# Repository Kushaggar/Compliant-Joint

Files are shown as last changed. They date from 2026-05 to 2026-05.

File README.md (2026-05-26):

# Translational Constraint Joint with 5 Degrees of Freedom

**Research Project | Mechatronics Lab, IIT Delhi**
**Supervised by Prof. Jitendra P. Khatait & Subrat (PhD Student)**

A compliant mechanism designed to constrain translation along the Y-axis while 
allowing controlled motion across 4 remaining DOFs. Stiffness values were derived 
analytically and validated against ANSYS static structural simulations.

---

## Overview

Traditional joints rely on sliding or rolling contact to guide motion — introducing 
friction, wear, and assembly complexity. This compliant mechanism achieves the same 
constraint behavior through elastic deformation of flexible members, with no moving 
parts, no lubrication, and no assembly required.

The joint constrains **1 DOF (Translation in Y)** while permitting:
- Rotation in X or Z axis
- Rotation in Y axis
- Translation in X axis
- Translation in Z axis

---

## Geometry

| Parameter | Value |
|---|---|
| Outer Diameter | 25 mm |
| Total Length | 106 mm |
| Flexure Thickness (t) | 0.50 mm |
| Flexure Radius (r) | R1.50 mm |
| Inner Radius | R5.00 mm |

---

## Specifications

| Motion | Displacement Range | Stiffness (Simulation) | Stiffness (Analytical) | Max Stress |
|---|---|---|---|---|
| Rotation X or Z | ±2.2° | 16.6 Nm/rad | 18.1 Nm/rad | 167.36 MPa |
| Rotation Y | ±4.6° | 21.86 Nm/rad | 21.81 Nm/rad | 308.35 MPa |
| Translation X | ±0.5 mm | 35.3 N/mm | 40.6 N/mm | 186.61 MPa |
| Translation Z | ±0.5 mm | 19.318 N/mm | 21.34 N/mm | 162.13 MPa |
| Translation Y | Constrained | 84745.76 N/mm | 94339.62 N/mm | — |

---

## Analytical Formulations

**Rotation in X or Z Axis:**

$$\theta = \sin^{-1}\left(\frac{l+r+t}{\sqrt{(l+r)^2+\left(\frac{d}{2}\right)^2}}\right) - \sin^{-1}\left(\frac{l+r}{\sqrt{(l+r)^2+\left(\frac{d}{2}\right)^2}}\right)$$

**Rotation in Y Axis:**

$$\theta = \sin^{-1}\left(\frac{2t}{\sqrt{t^2+\left(\frac{d}{2}\right)^2}}\right) - \sin^{-1}\left(\frac{t}{\sqrt{t^2+\left(\frac{d}{2}\right)^2}}\right)$$

**Translation in X or Z Axis:**

$$\delta = \pm t$$

---

## Simulation vs Analytical — Summary

| Motion | % Error |
|---|---|
| Rotation X/Z | 9% |
| Rotation Y | 0.2% |
| Translation X | 15% |
| Translation Z | 10% |
| Translation Y | 11.3% |

All results within acceptable range for compliant mechanism design at this scale.
Rotation Y shows near-perfect agreement (0.2%) between simulation and analytical model.

**Critical Buckling Load (Translation Y, Euler's formula):** 2.3 × 10⁴ N

---

## Tools & Methods
- **CAD:** SolidWorks
- **Simulation:** ANSYS Workbench — Static Structural
- **Validation:** Analytical beam theory (ML/EI, PL³/3EI, torsion stiffness formulations)

---

## Files

| File | Description |
|---|---|
| *5 DOF* | SolidWorks part file |
| `5 DOF.pdf` | Drawing file |
| `Translation Constraint Joint with 5 DOF.pdf` | Full project report with simulation results |

---

## Context
This work was completed during a research internship at the **Mechatronics Lab, IIT Delhi**
under the supervision of **Prof. Jitendra P. Khatait**.

**Portfolio:** [kushank.vercel.app](https://kushank.vercel.app)

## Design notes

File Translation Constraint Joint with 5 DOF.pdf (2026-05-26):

# Translation Constraint Joint with Five Degrees of Freedom

## A Report

by

# Kushank Aggarwal

## (B.tech student at Delhi Technological University)

## (Intern at Mechatronics Lab, IIT Delhi)

## Supervised by

# Prof. Jitendra P. Khatait

# Subrat (Ph.D Student)

# CAD MODEL

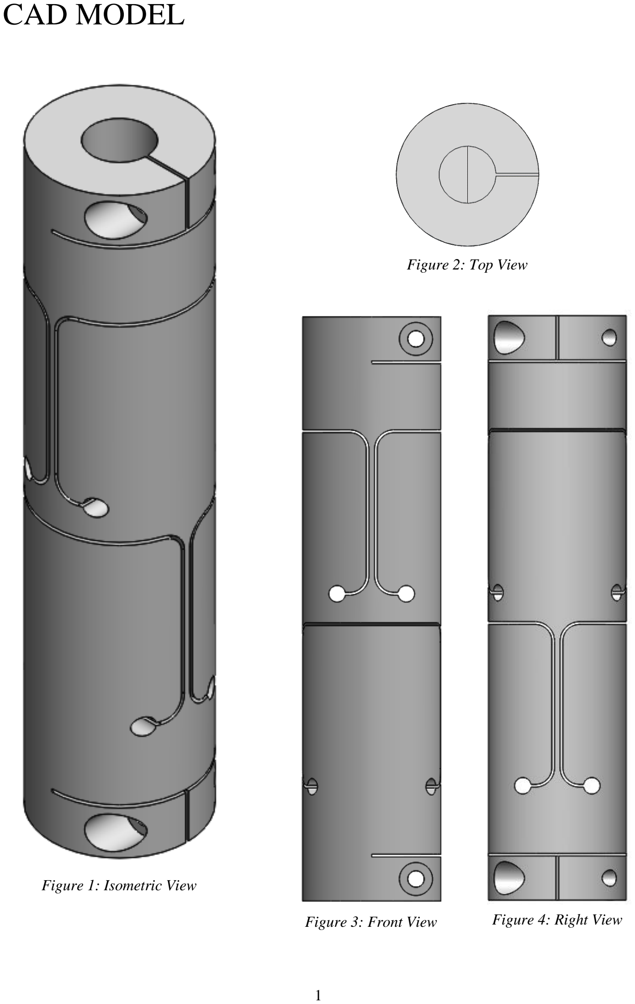
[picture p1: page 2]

Figure 1: Isometric View

Figure 3: Front View

Figure 2: Top View

Figure 4: Right View

# CAD Drawing

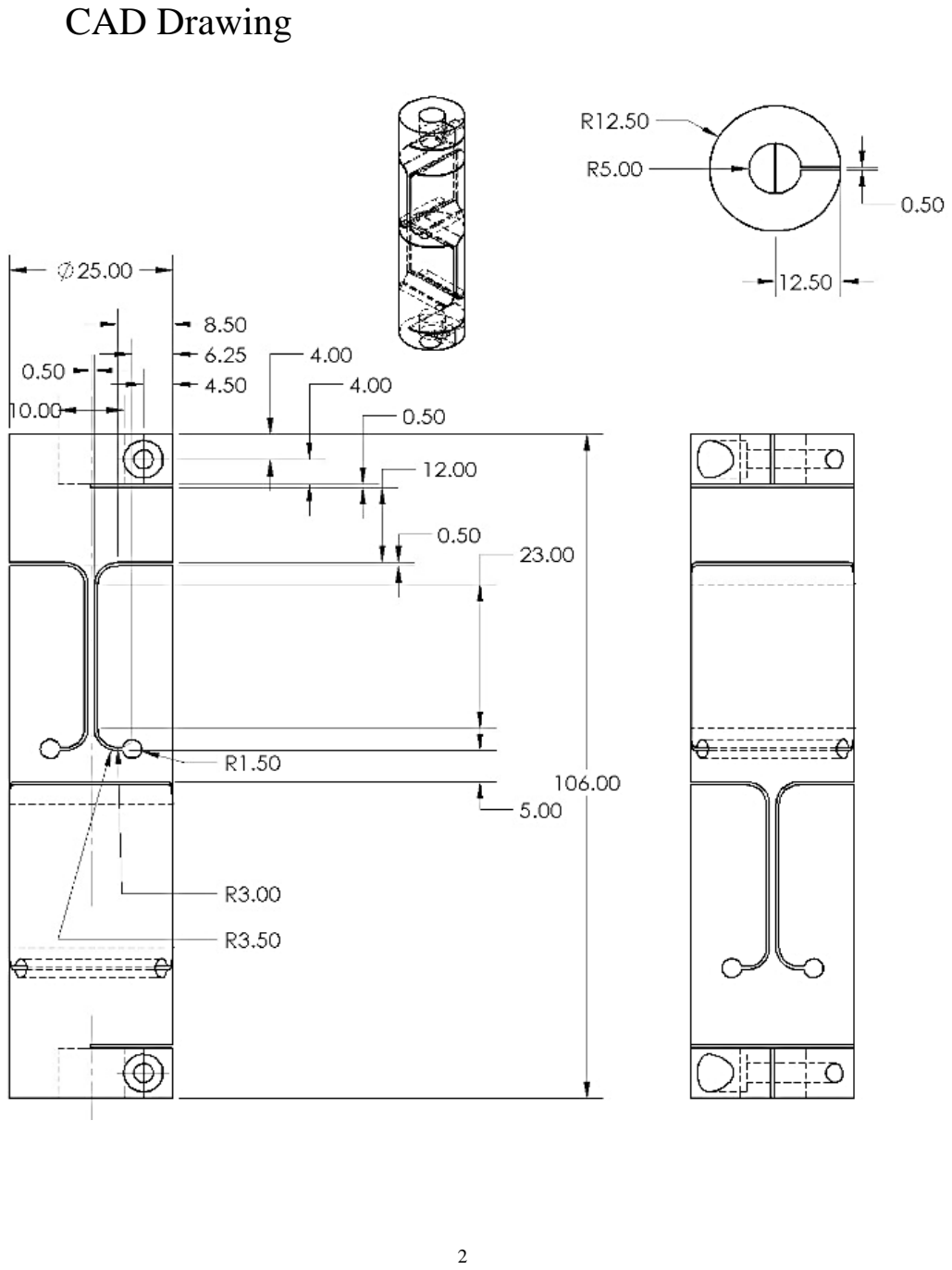
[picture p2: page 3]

# Specifications

# Range of motion with changing parameters

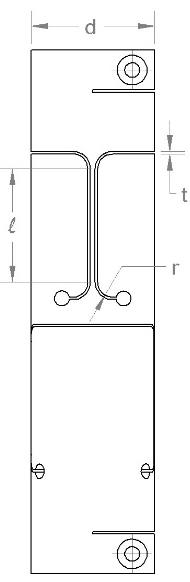
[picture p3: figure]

## 1. Rotation in X or Z Axis:

θ = sin⁻¹
(

l + r + t
√(l + r)
2 + (

d
2

)

2 | 2

)

− sin⁻¹
(

l + r
√(l + r)
2 + (

d
2

)

2 | 2

)

## 2. Rotation in Y Axis:

θ = sin⁻¹
(

2t
√(t)
2 + (

d
2

)

2 | 2

)

− sin⁻¹
(

t
√(t)
2 + (

d
2

)

2 | 2

)

## 3. Translation in X or Z Axis:

δ = ±t

Motion | Displacement Range | Stiffness | Maximum Stress
Simulation | Analytical
Rotation in X or Z Axis | ±2.2º | 16.6 Nm/rad | 18.1 Nm/rad | 167.36 MPa
Rotation in Y Axis | ±4.6º | 21.86 Nm/rad | 21.81 Nm/rad | 308.35 MPa
Translation in X Axis | ±0.5 mm | 35.3 N/mm | 40.6 N/mm | 186.61 MPa
Translation in Z Axis | ±0.5 mm | 19.318 N/mm | 21.34 N/mm | 162.13 MPa
Translation in Y Axis | Constraint | 84745.76 N/mm | 94339.62 N/mm | -

## 1. Rotation in X or Z Axis

Torque = 665 Nmm

θ = 0.0399 rad (from simulation)

Using the formula, θ =

ML
EI

, for slope due to a moment, we get the value θ = 0.0367 rad

Value of stiffness calculated from simulation, K= 16.6 Nm/rad

Value of stiffness calculated from formula, K= 18.1 Nm/rad

Percentage error = 9%

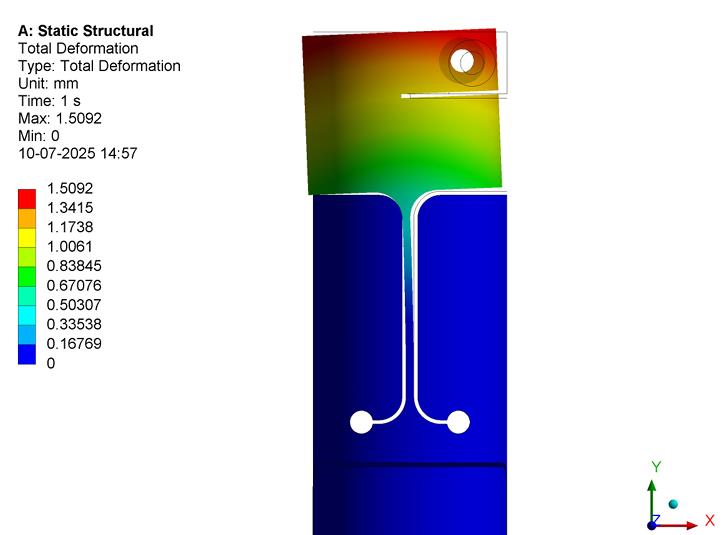
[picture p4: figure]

Figure 5: Displacement

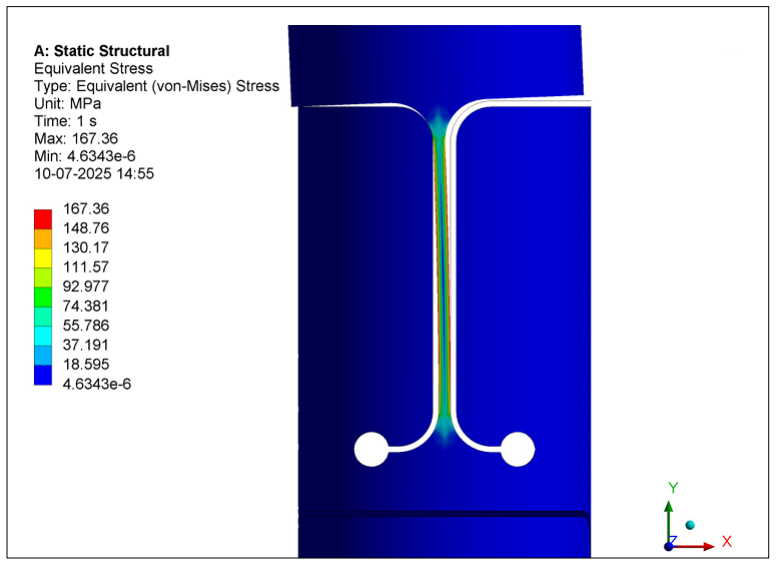
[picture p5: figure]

Figure 6: Stress

## 2. Rotation in Y Axis

Torque = 1800 Nmm

θ = 0.0823 rad (from simulation)

Using the formula, k = ab

3

[

16
3

− 3.36 b
a

(1 −

b

4
12a⁴

)] … (a ≥ b) , for coefficient of stiffness, we

get k = 129.973

Also, putting the value of k in the formula, k =

Tl

θG , we get the value of stiffness i.e. T
θ

=

kG
l

, but this
value of stiffness would be just for a single section, and in order to find the net stiffness we need to multiply it by 2.

Value of stiffness calculated from simulation, K= 21.86 Nm/rad

Value of stiffness calculated from formula, K= 21.81 Nm/rad

Percentage error = 0.2%

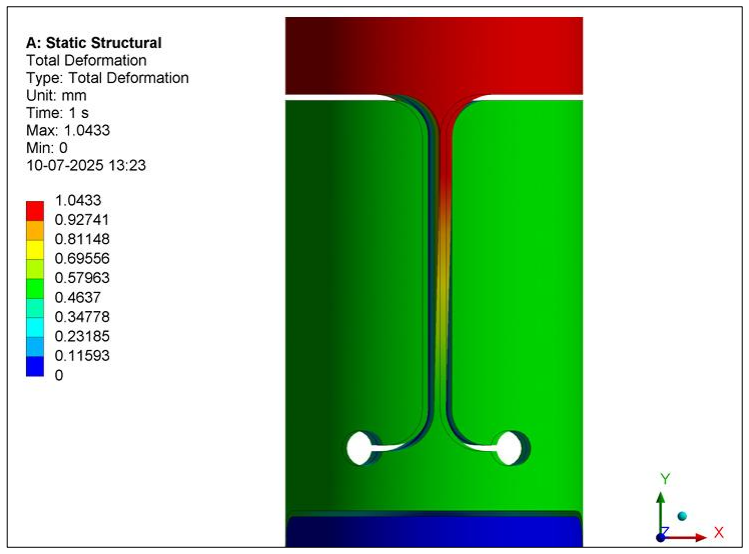
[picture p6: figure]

Figure 7: Displacement

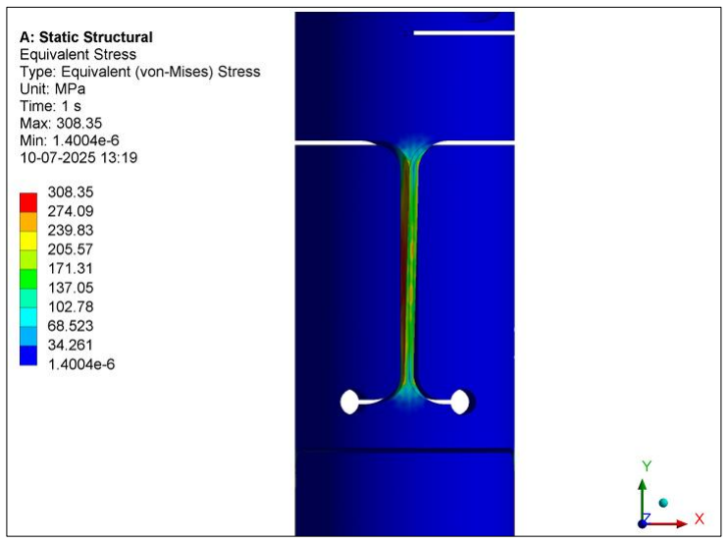
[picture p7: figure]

Figure 8: Stress

## 3. Translation in X Axis

Force = 17 N

δ = 0.4805 mm (from simulation)

Using the formula, δ =

ML

2

2EI

, for deflection due to a moment, we get the value δ = 0.253 mm

And using the formula, δ =

PL

3

3EI

, for deflection due to a load, we get the value δ = 0.165 mm

δnet = 0.418 mm

Value of stiffness calculated from simulation, K= 35.3 N/mm

Value of stiffness calculated from formula, K= 40.6 N/mm

Percentage error = 15%

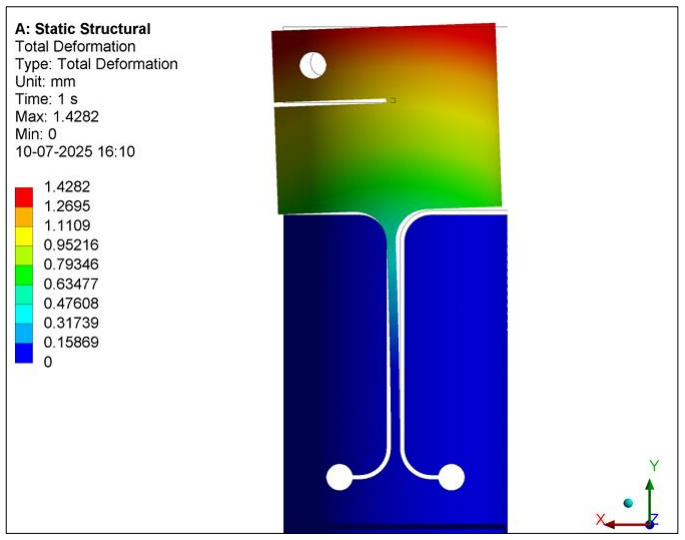
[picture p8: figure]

Figure 9: Displacement

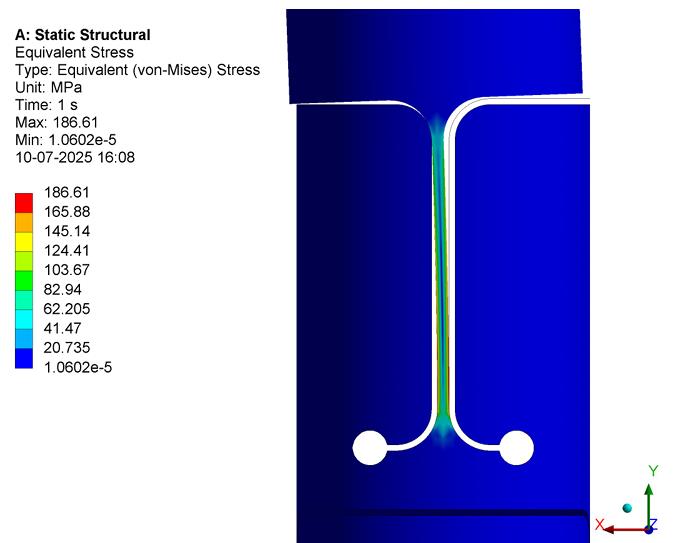
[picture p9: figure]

Figure 10: Stress

## 4. Translation in Z Axis

Force = 8.5 N

δ = 0.440 mm (from simulation)

Using the formula, δ =

ML

2

2EI

, for deflection due to a moment, we get the value δ = 0.315 mm

And using the formula, δ =

PL

3

3EI

, for deflection due to a load, we get the value δ = 0.0827 mm

δnet = 0.3983 mm

Value of stiffness calculated from simulation, K= 19.318 N/mm

Value of stiffness calculated from formula, K= 21.34 N/mm

Percentage error = 10%

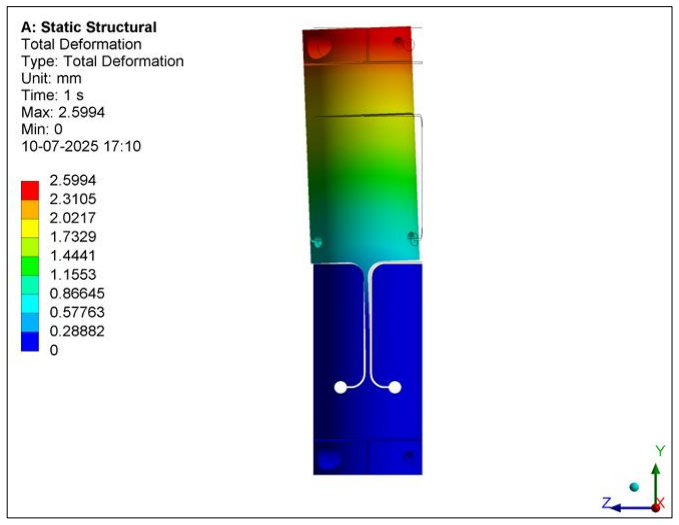
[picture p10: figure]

Figure 11: Displacement

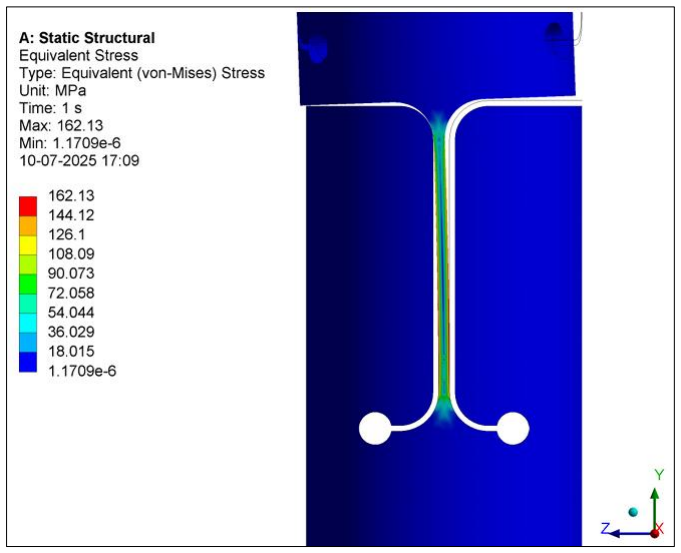
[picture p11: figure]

Figure 12: Stress

## 5. Translation in Y Axis

Force = 50 N

δ = 5.9 x 10⁻⁴ mm (from simulation)

Using the formula, δ =

PL
AE

, we get the value δ = 5.3 x 10⁻⁴ mm

Value of stiffness calculated from simulation, K= 84745.76 N/mm

Value of stiffness calculated from formula, K= 94339.62 N/mm

Percentage error = 11.3%

Using the Euler’s formula, P =

π

2EI

4L

2

, for a column fixed at one end and free at the other, we can calculate the value of the

Critical Buckling Load = 2.3 x 10⁴ N

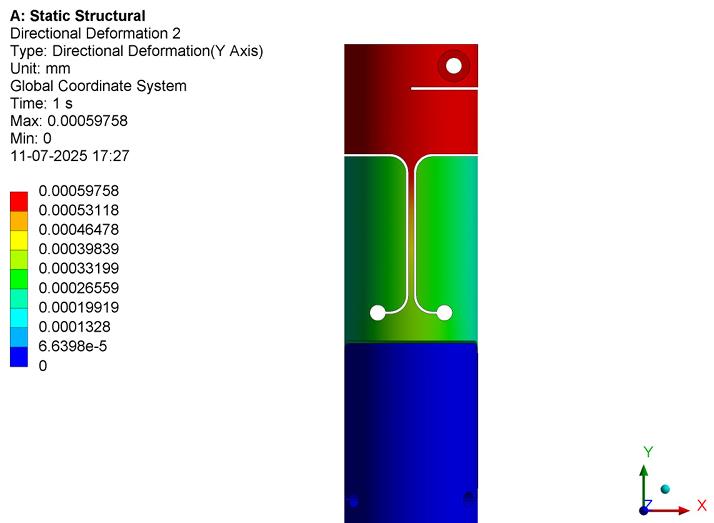
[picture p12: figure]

Figure 13: Displacement

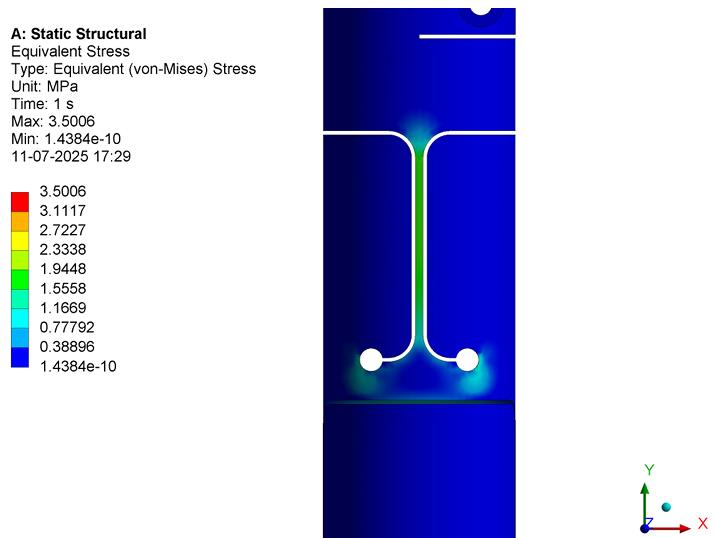
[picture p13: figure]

Figure 14: Stress

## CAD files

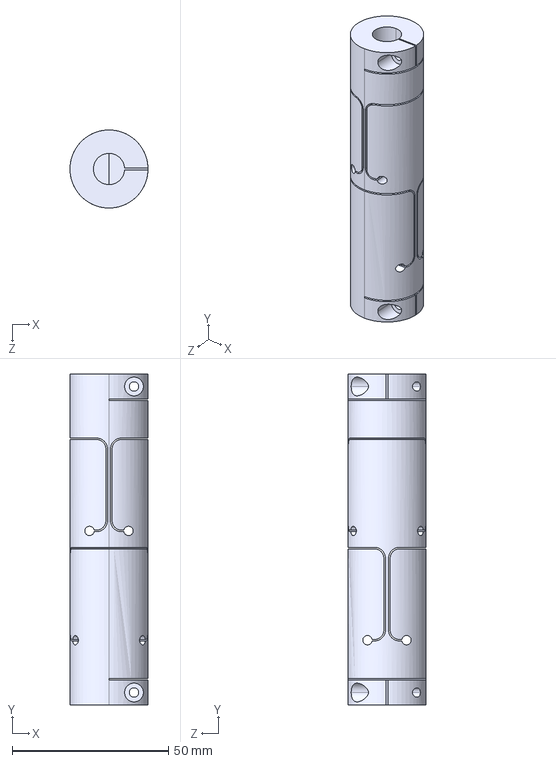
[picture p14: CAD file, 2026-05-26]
5 DOF.STEP
25.0 x 106.0 x 25.0 mm

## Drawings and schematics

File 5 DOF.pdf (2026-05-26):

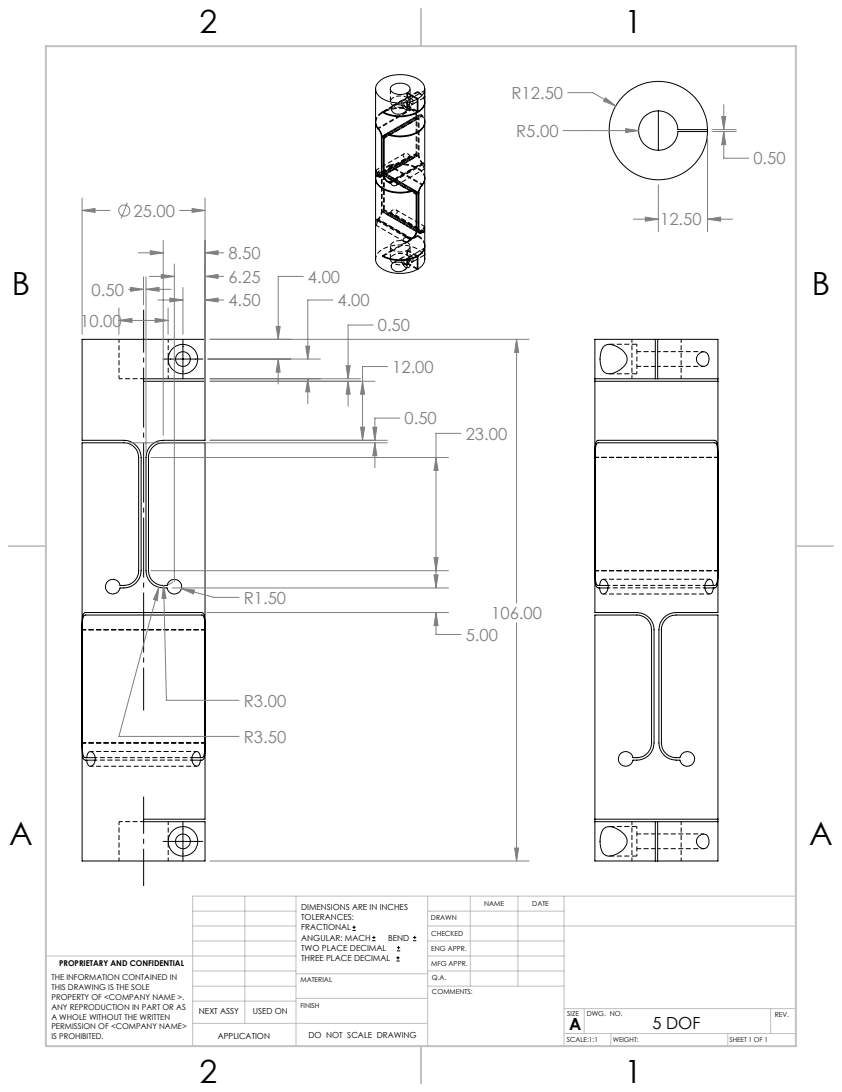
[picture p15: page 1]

TOLERANCES: FRACTIONAL ANGULAR: MACH BEND TWO PLACE DECIMAL THREE PLACE DECIMAL | | NAME | DATE DIMENSIONS ARE IN INCHES

DRAWN
CHECKED
ENG APPR.

PROPRIETARY AND CONFIDENTIAL THE INFORMATION CONTAINED IN THIS DRAWING IS THE SOLE PROPERTY OF <COMPANY NAME >. ANY REPRODUCTION IN PART OR AS A WHOLE WITHOUT THE WRITTEN PERMISSION OF <COMPANY NAME> IS PROHIBITED. | | | MFG APPR.

MATERIAL | Q.A.

NEXT ASSY | USED ON | FINISH

SIZE A | DWG. NO. 5 DOF | REV.

APPLICATION | | DO NOT SCALE DRAWING

SCALE:1:1 | WEIGHT: | SHEET 1 OF 1
